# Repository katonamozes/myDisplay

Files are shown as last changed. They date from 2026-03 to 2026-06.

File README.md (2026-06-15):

This is my WiFi-connected Spotify display that shows album art and track information on a 1.8" TFT screen, it also has 6 buttons. 3 for controling volume and 3 for the songs. I made this to learn about using wifi in an esp32 project and so that I could control my media easier when working on other projects. If I was already learning this stuff I also wanted to have something that I could actually use and this was a great way to do that as I listen to music very often and it's great that I now have a seperate device where I can control it.

Before uploading the file to your arduino you need to put in the details for your wifi and spotify client.
This is what it looks like when assembled:




Wiring diagram: 

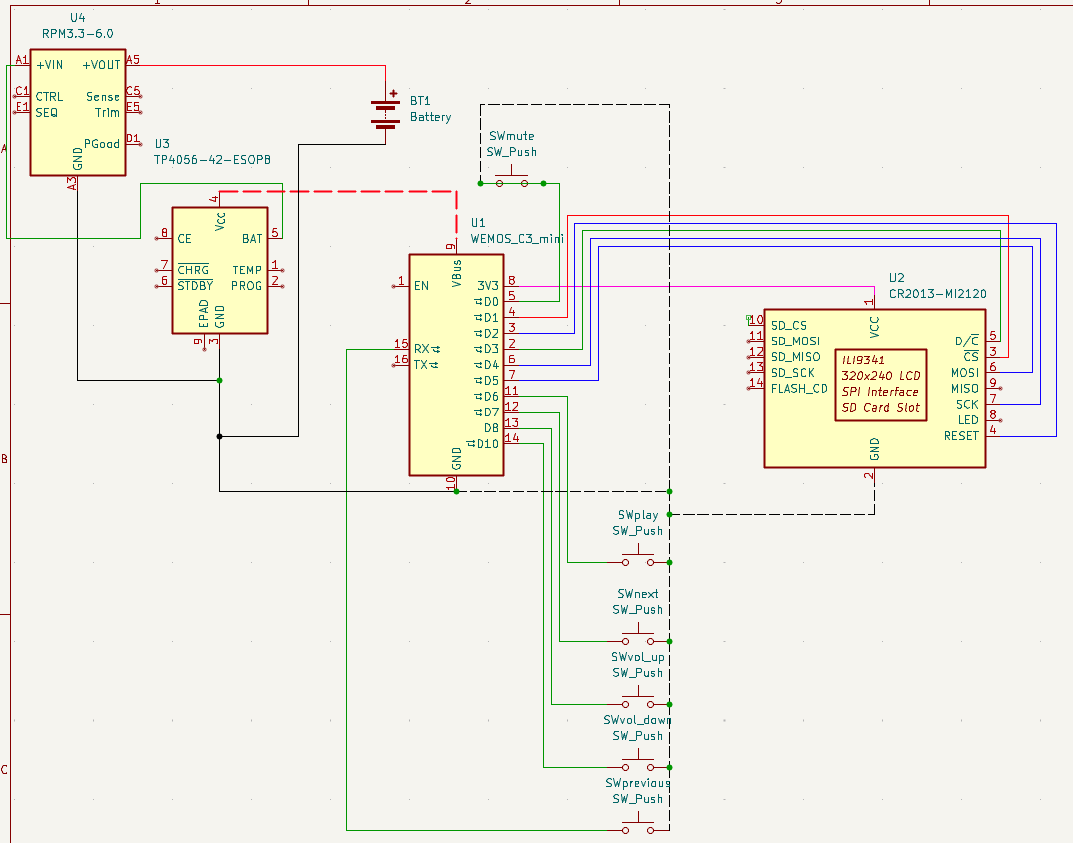
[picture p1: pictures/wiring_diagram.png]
Wiring diagram


Case: 

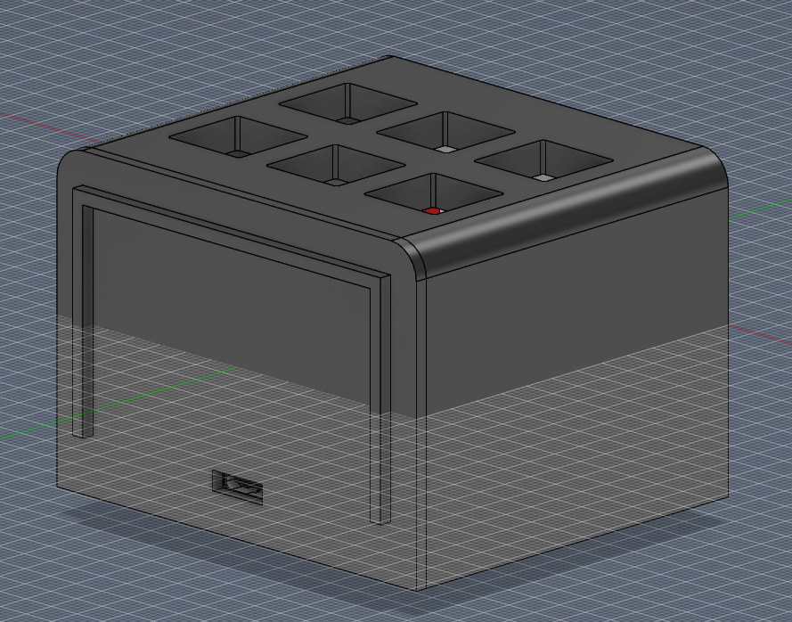
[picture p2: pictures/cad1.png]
cad1
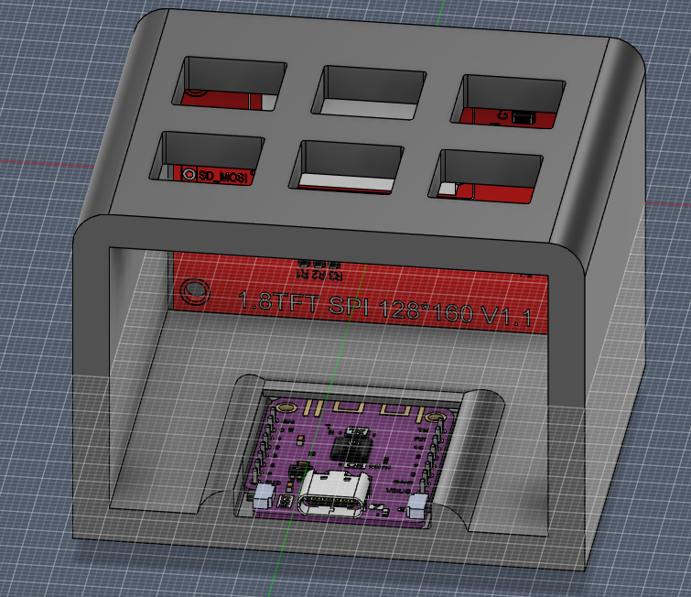
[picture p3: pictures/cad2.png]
cad2
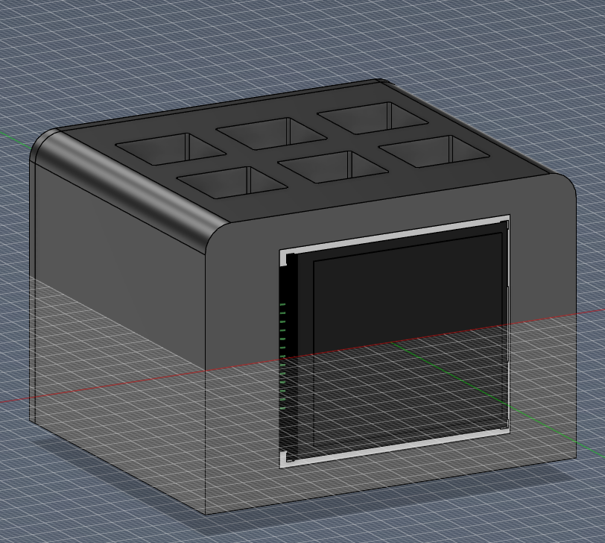
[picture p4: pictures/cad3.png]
cad3
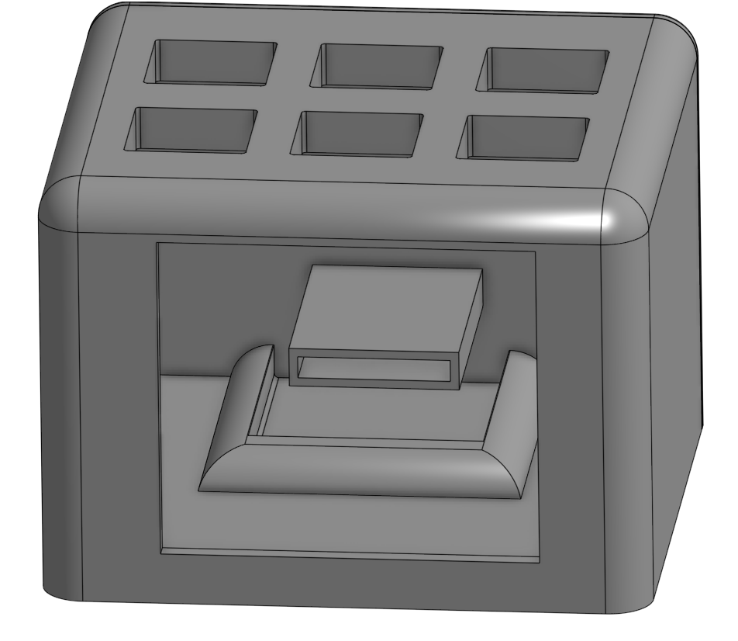
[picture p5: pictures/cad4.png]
cad4
   

| Supplier | Amount | Component	| Price |	Link |
| ---- | ---- | ---- | ----| ---- |
| Lolin | 1x |	ESP32-C3 Mini |	$6.26	| [link to aliexpress](https://nl.aliexpress.com/item/1005004740051202.html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)
| Unknown | 1x |	1.8inch tft display |	$2.97	| [link to aliexpress](https://nl.aliexpress.com/item/1005007038447382.html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)
| Mingrong LED Store | 1x	| 10 piece bundle of self drilling m3 screws |	$2.10 |	[link to aliexpress](https://nl.aliexpress.com/item/1005008941241500.html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)
| Kailh Switch Official Store | 6x |	keyboard switches	| $5.54	| [link to aliexpress](https://nl.aliexpress.com/item/1005006224673721.html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)
| SZHJW Technology Store | 1x	| 0.9-5V To 5V DC-DC Step-Up |	$0.94	| [link to aliexpress](https://nl.aliexpress.com/item/1005005624977910.html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)
| MWSS PCB Store | 1x |	5V 1A Type-c TP4056 Lithium Battery charging module |	$0.86	| [link to aliexpress](https://nl.aliexpress.com/item/1005004408520078.html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)
| Teranty Official Store | 1x	| 3.7v lithium ion battery |	$6.34	| [link to aliexpress](https://nl.aliexpress.com/item/1005001493575875.html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)
| Shop1105235778 Store | 1x	| wires	| $1.08	| [link to aliexpress](https://nl.aliexpress.com/item/1005011849498412.html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)
| Gen Z Store | 1x |	solder wire |	$2.73	| [link to aliexpress](https://nl.aliexpress.com/item/1005008618276811.html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)

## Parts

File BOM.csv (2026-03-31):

Supplier | Amount | Component | Price | Link
Lolin | 1x | ESP32-C3 Mini | $6.26 | https://nl.aliexpress.com/item/1005004740051202.html?mp=1
Unknown | 1x | 1.8inch tft display | $2.97 | https://nl.aliexpress.com/item/1005007038447382.html?mp=1
Mingrong LED Store | 1x | 10 piece bundle of self drilling m3 screws | $2.10 | https://nl.aliexpress.com/item/1005008941241500.html?curPageLogUid=rQ9zxD0Mg27H
Kailh Switch Official Store | 6x | keyboard switches | $5.54 | https://nl.aliexpress.com/item/1005006224673721.html?curPageLogUid=VVRvhW7w6maI
SZHJW Technology Store | 1x | 0.9-5V To 5V DC-DC Step-Up | $0.94 | https://nl.aliexpress.com/item/1005005624977910.html?curPageLogUid=s6AZ9qftx93J
MWSS PCB Store | 1x | 5V 1A Type-c TP4056 Lithium Battery charging module | $0.86 | https://nl.aliexpress.com/item/1005004408520078.html?mp=1
Teranty Official Store | 1x | 3.7v lithium ion battery | $6.34 | https://nl.aliexpress.com/item/1005001493575875.html?curPageLogUid=TkOGJnl1Wd3L
Shop1105235778 Store | 1x | wires | $1.08 | https://nl.aliexpress.com/item/1005011849498412.html?curPageLogUid=Ett3w0GubM8b
Gen Z Store | 1x | solder wire | $2.73 | https://nl.aliexpress.com/item/1005008618276811.html?mp=1

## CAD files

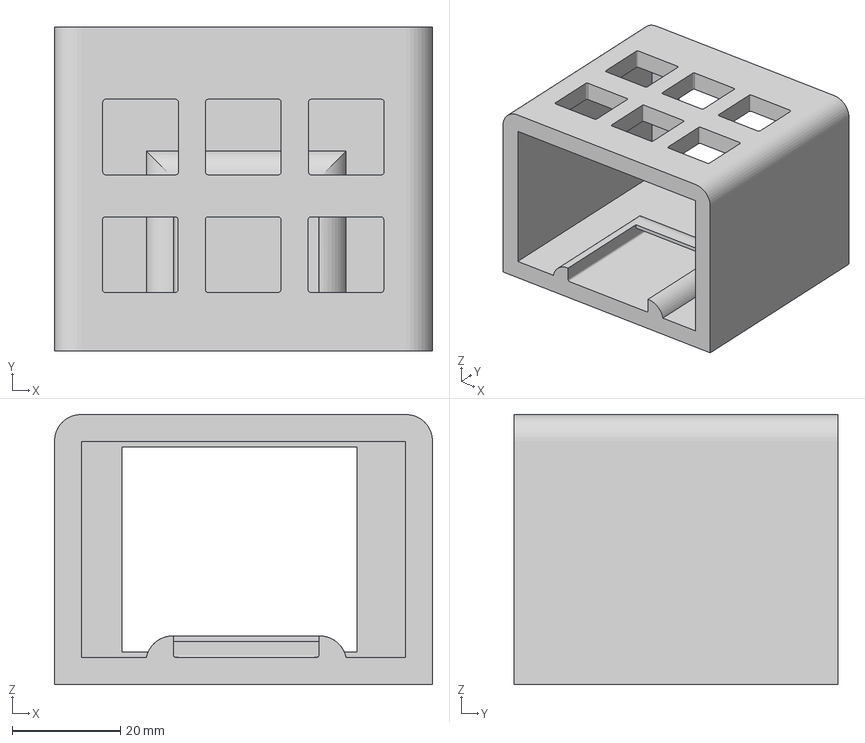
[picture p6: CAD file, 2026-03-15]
CAD/Body1.3mf
70.0 x 60.0 x 50.0 mm

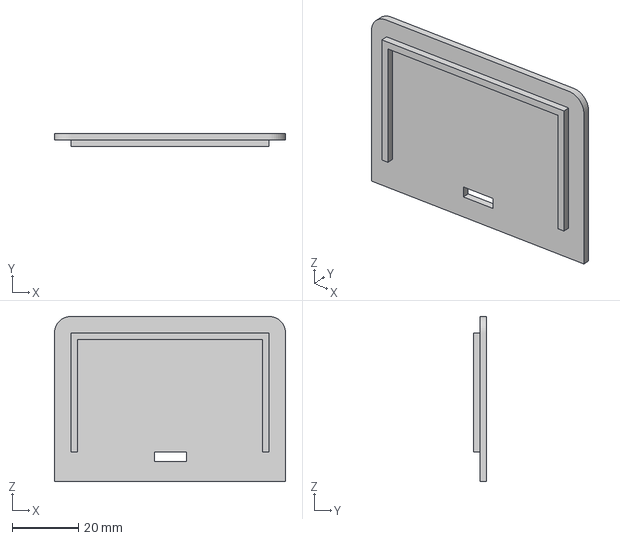
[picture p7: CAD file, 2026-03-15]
CAD/Body2.3mf
70.0 x 4.00 x 50.0 mm

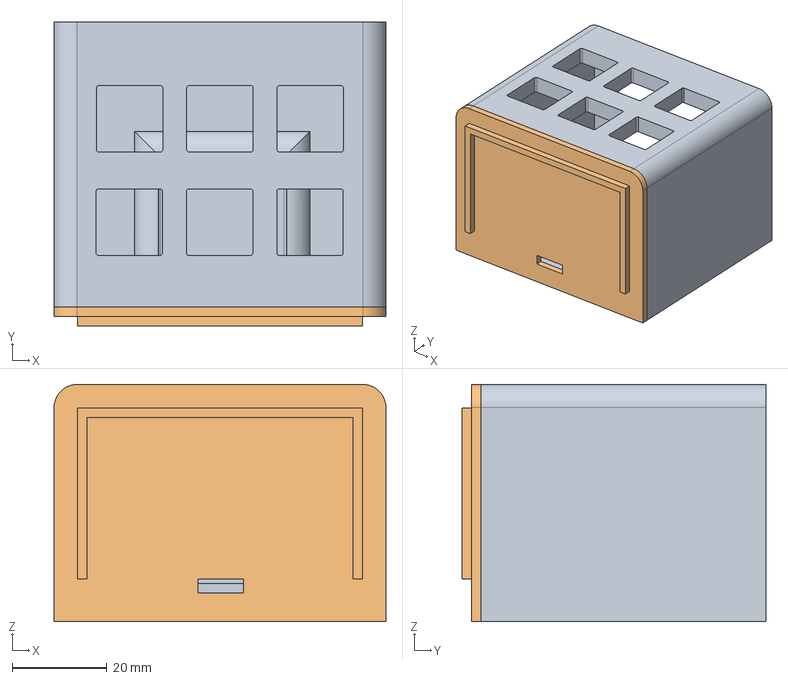
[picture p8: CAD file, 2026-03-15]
CAD/SpotifyDisplay.step
70.0 x 64.0 x 50.0 mm

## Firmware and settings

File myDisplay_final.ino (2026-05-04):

#include <Arduino.h>
#include <ArduinoJson.h>
#include <Adafruit_GFX.h>
#include <Adafruit_ST7735.h>
#include <SpotifyEsp32.h>
#include <SPI.h>
#include <WiFi.h>

#define TFT_CS 1
#define TFT_RST 2
#define TFT_DC 3
#define TFT_SCLK 4
#define TFT_MOSI 5
#define BTN_PLAY_PAUSE 6
#define BTN_NEXT       7
#define BTN_VOL_UP     8
#define BTN_VOL_DOWN   10
#define BTN_MUTE    0
#define BTN_PERVIOUS   21

int currentVolume = 50; // Local tracker for volume
char* SSID = "WIFI_NAME";
const char* PASSWORD = "WIFI_PASSWORD";
const char* CLIENT_ID = "SPOTIFY_ID";
const char* CLIENT_SECRET = "SPOTIFY_SECRET_PASSWORD";
unsigned long lastSpotifyCheck = 0; 
const unsigned long spotifyInterval = 1000; // 1 second

String lastArtist;
String lastTrackname;

Spotify sp(CLIENT_ID, CLIENT_SECRET);
Adafruit_ST7735 tft = Adafruit_ST7735(TFT_CS, TFT_DC, TFT_MOSI, TFT_SCLK, TFT_RST);


void setup() {
    Serial.begin(115200);
    pinMode(BTN_PLAY_PAUSE, INPUT_PULLUP);
    pinMode(BTN_NEXT, INPUT_PULLUP);
    pinMode(BTN_VOL_UP, INPUT_PULLUP);
    pinMode(BTN_VOL_DOWN, INPUT_PULLUP);
    pinMode(BTN_MUTE, INPUT_PULLUP);
    tft.initR(INITR_BLACKTAB); // the type of screen
    tft.setRotation(1); // this makes the screen landscape! remove this line for portrait
    Serial.println("TFT Initialized!");
    tft.fillScreen(ST77XX_BLACK); // make sure there is nothing in the buffer

    WiFi.begin(SSID, PASSWORD);
    Serial.print("Connecting to WiFi...");
    while(WiFi.status() != WL_CONNECTED)
    {
        delay(1000);
        Serial.print(".");
    }
    Serial.printf("\nConnected!\n");

    tft.setCursor(0,0); // make the cursor at the top left
    tft.write(WiFi.localIP().toString().c_str()); // print out IP on the screen

    sp.begin();
    while(!sp.is_auth()){
        sp.handle_client();
    }
    Serial.println("Authenticated");
}

void loop()
{
    // Only check Spotify if 1 second has passed
    if (millis() - lastSpotifyCheck >= spotifyInterval) {
        lastSpotifyCheck = millis(); // Reset the timer

        String currentArtist = sp.current_artist_names();
        String currentTrackname = sp.current_track_name();

        // Check if the artist changed
        if (lastArtist != currentArtist && currentArtist != "Something went wrong" && !currentArtist.isEmpty()) {
            tft.fillScreen(ST77XX_BLACK); 
            lastArtist = currentArtist;
            tft.setCursor(10, 10);
            tft.setTextColor(ST77XX_WHITE);
            tft.setTextSize(1);
            tft.print(lastArtist.c_str());
        }

        // Check if the track changed
        if (lastTrackname != currentTrackname && currentTrackname != "Something went wrong" && currentTrackname != "null") {
            tft.fillRect(0, 40, 160, 30, ST77XX_BLACK); 
            lastTrackname = currentTrackname;
            tft.setCursor(10, 40);
            tft.setTextColor(ST77XX_CYAN);
            tft.print(lastTrackname.c_str());
        }
    }

    // --- Button logic stays OUTSIDE the if-block ---
    // This allows buttons to remain responsive regardless of the 1-second timer.

    //1. Pause/Play
    if (digitalRead(BTN_PLAY_PAUSE) == LOW) {
        sp.start_a_users_playback(); 
        delay(300); // Simple debounce
    }

    // 2. Next Track
    if (digitalRead(BTN_NEXT) == LOW) {
        sp.skip_to_next();
        delay(300);
    }

    //3. Previous track
    if (digitalRead(BTN_PERVIOUS) == LOW) {
        sp.skip_to_previous();
        delay(300);
    }

    // 4. Volume Control
    if (digitalRead(BTN_VOL_UP) == LOW) {
        currentVolume = min(100, currentVolume + 10);
        sp.set_volume(currentVolume);
        Serial.printf("Volume: %d\n", currentVolume);
        delay(200);
    }

    if (digitalRead(BTN_VOL_DOWN) == LOW) {
        currentVolume = max(0, currentVolume - 10);
        sp.set_volume(currentVolume);
        Serial.printf("Volume: %d\n", currentVolume);
        delay(200);
    }
        if (digitalRead(BTN_MUTE) == LOW) {
        currentVolume = max(0, currentVolume - currentVolume);
        sp.set_volume(currentVolume);
        Serial.printf("Volume: %d\n", currentVolume);
        delay(200);
    }
}

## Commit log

2026-03-14 Add Spotify display and control functionality
    This Arduino sketch connects to WiFi and Spotify, displaying the current artist and track on a TFT screen. It includes button controls for play/pause, next, previous, volume up/down, and mute.
2026-03-15 Update README with wiring diagram information
    Add wiring diagram note to README
2026-03-15 Rename Schermafbeelding 2026-03-15 093116.jpeg to wiring-diagram
2026-03-15 Add wiring diagram image to README
2026-03-15 Update image path for wiring diagram in README
2026-03-15 Update README with wiring and case diagrams
    Added wiring diagram and case images to README.
2026-03-15 Add BOM.csv with component list and links
    [BOM.csv]
2026-03-15 Add BOM section with component links to README
    Added a Bill of Materials (BOM) section with links to components.
2026-03-15 Update README with assembly tutorial note
    Added a note about an upcoming assembly tutorial.
2026-03-15 Update BOM with prices for components
2026-03-15 Add prices to BOM items
    Updated product listings with prices for clarity.
    [BOM.csv]
2026-03-15 Add header and update BOM.csv with components
    [BOM.csv]
2026-03-16 Add keyboard switches to BOM with pricing and links
    [BOM.csv]
2026-03-16 Add keyboard switches to the components list
2026-03-16 Add new product links to README
    Added new product links for DC-DC Step-Up converter and TP4056 lithium battery charger.
2026-03-16 Modify BOM.csv with updated item details
    Updated quantities and prices for several items.
    [BOM.csv]
2026-03-16 Update BOM.csv with new battery information
    [BOM.csv]
2026-03-31 Reformat BOM.csv for better readability
    [BOM.csv]
2026-03-31 Update wire and add solder wire in BOM
    Updated BOM.csv to replace the old wire entry with a new one and added a solder wire entry.
    [BOM.csv]
2026-03-31 Update BOM.csv with new component links and prices
    [BOM.csv]
2026-03-31 Update quantities and prices in BOM.csv
    Updated the BOM.csv file to reflect new quantities and prices for components.
    [BOM.csv]
2026-03-31 Remove unnecessary GitHub Pages link
    Removed GitHub Pages link from BOM.csv
    [BOM.csv]
2026-03-31 Add supplier details to BOM.csv
    Added supplier information for each component in BOM.
    [BOM.csv]
2026-06-15 Enhance README with assembly images and details
    Added images of the assembled device and updated project description.
